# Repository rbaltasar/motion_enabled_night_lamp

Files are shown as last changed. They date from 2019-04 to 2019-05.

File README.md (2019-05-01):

# Introduction and background
This project is about a LED lamp that switches ON and OFF depending on light and motion conditions.
We have all experienced the situation when, at night, nature calls, and we need to make a quick trip to the bathroom. Doing this trip in the darkness can be quite an adventure for some people and in some rooms, but switching the main light of the room might not be the best solution in some cases: annoys the partner, is far away, to bright for your sleepy eyes...
The solution to this problem is easy! A faint light that switches on when you go to the bathroom and switches off once you are already back in bed.
Trying to find such a device on the market, I find many motion-enabled lights. A little bit problematic is that most of them are designed for outdoors lighting, so the light is quite powerful. But the biggest problem is that all these lights are controlled by an unique motion sensor: any motion detected will trigger the light. This could be you waking up and going to the bathroom, or you just moving in the bed.
I could not find any device in the market that focuses on preventing false positives, and this is the most important feature I would ask to a device that might wake me up randomly at night.

# Proposed solution
The ideal solution to this problem would be a device that only goes off when you are already up and walking towards your destination, but does not go off when you or any other thing in your room moves a little bit (e.g: curtains, clothes falling from the chair…).
I want to define a virtual line that  when is crossed, triggers the light. I also want this only happens if we really need some extra light and I want the light to be on as long as I need it to be on and to switch off automatically when I no longer need it.

The first thing that you could think of when I talk about “crossing a virtual line” may be a ultrasonic distance sensor (e.g: HC-SR04). These sensors are based on sound reflection, and they do not work very good with clothes. Besides, having a single sensor keeps high the probabilities of false positives.
This solution consists of two PIR motion sensors placed in such a way that their areas of detection do not overlap. The area of “no detection” will be the virtual line to cross. When both sensors detect a motion and the time difference between the detection is short enough, we can assume that the virtual line has been crossed. If the time difference between detections is larger than a threshold, we can assume that the detection events are sporadic and not related to each other, so no action will be taken. This will exclude most of the false positives that would have triggered a device with a single motion sensor.

To ensure that the lamp only switches on when there is not enough light to see, the system will integrate a light sensor and define a light threshold above which the system will ignore motion events.
Depending on the configured lighting level of the LEDs, when the lamp is on it might trick the light sensor to think that there is enough ambient light to ignore motion events and go to “day” mode. This would trigger an oscillation going on with motion and off because of the light amount. To avoid this irritating behavior, the system is configured to consider the light amount only when the light is off.

To ensure the third requirement of being on until the light is no longer needed, once the system is on, a timer will start. Whenever a new motion event is detected, the timer will be restarted. When a timeout event happens, the light will switch off.

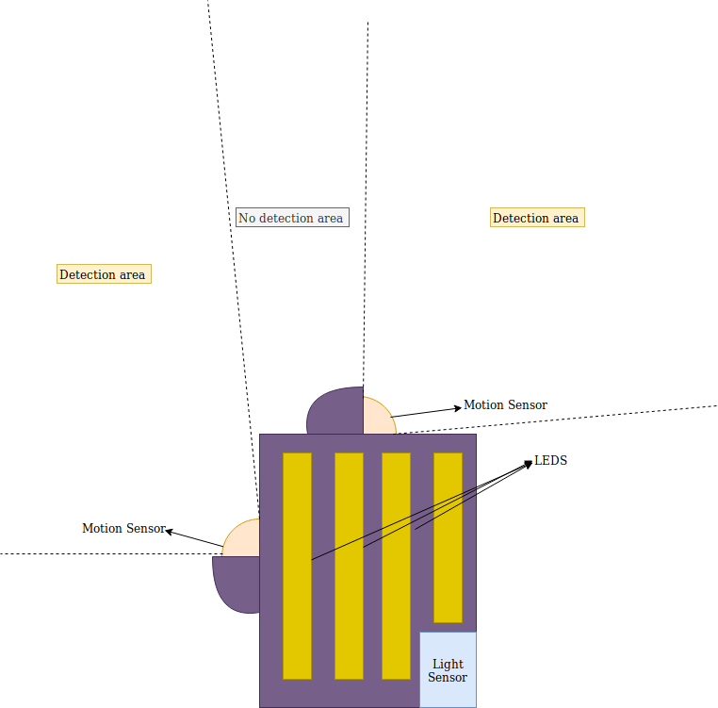
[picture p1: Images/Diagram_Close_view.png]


# The mechanics
This repository contains a 3D model of a box (base, top and cover) that is specifically designed to prevent overlapping of the two motion sensors.
It also leaves an open slot to allow the light sensor to “see”. I would recommend to cover it with a transparent material. The light threshold will need to be adapted to the light conditions of the room and the cover material chosen.

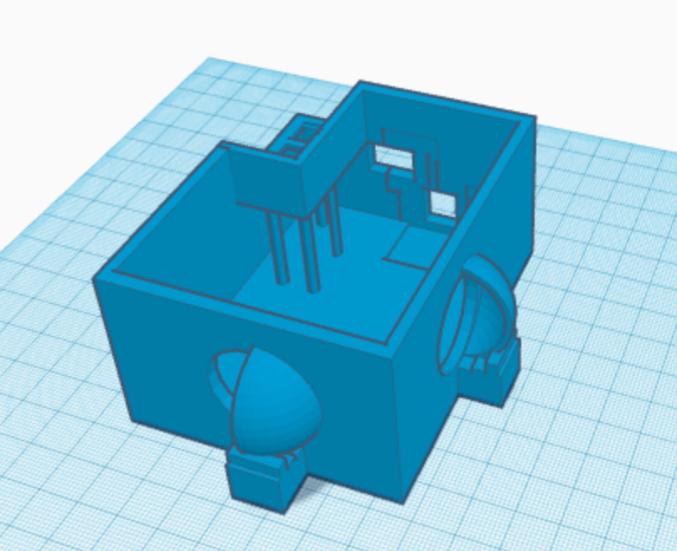
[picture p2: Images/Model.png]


I decided to embed the light in the box, to make a single-piece device, so I also left open slots for the LEDs. It is of course possible to modify the 3D design to place the LEDs in a different way, separate the lighting device from the “control” box…
It should also be doable to use a different lighting device, like a normal map controlled by a relay or an IR-controlled bulb.
I currently only support LED stripe as lighting device, any other method is not yet supported and would need to be implemented.
I might add support for other lighting devices in future updates of the project.

# The hardware
The device consists of the following hardware components:
* Arduino Nano.
* HC-SR501 PIR motion sensor (x2).
* BH1750 light sensor.
* WS2812B led stripe and 5v power supply. More information about how to handle and power this led stripe: https://www.pololu.com/product/2547
* 330 Ohm resistor.

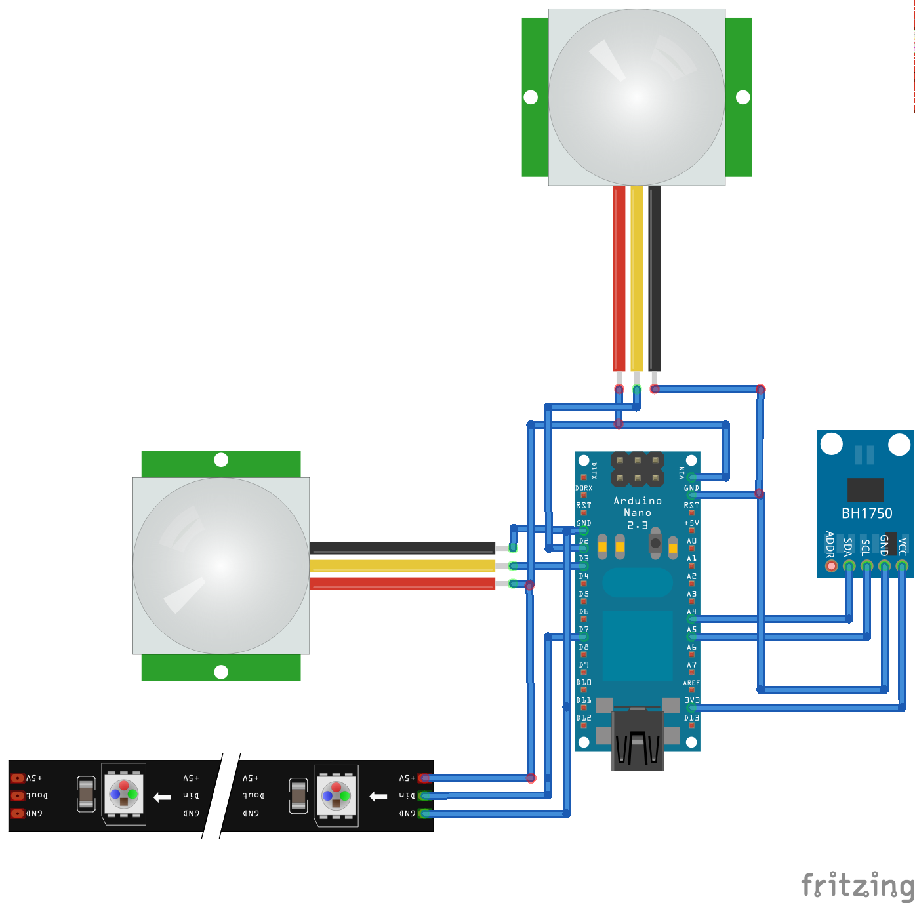
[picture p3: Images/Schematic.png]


# Software & Configuration
To configure the software and flash it into your Arduino, follow the next steps:
1. Clone this repository. Remember to do it recursively to get also the FastLED library.
2. Open the configuration file “config.h” and change the following parameters for your use case:
* NUM_LEDS: number of leds in your LED stripe. By default X LEDs fit in the given 3D model.
* LIGHT_THRESHOLD: above this value, the device is in “Day” mode and will ignore motion events. It is recommended to measure the light level in your room with the debug traces to find the right value.
* DETECTION_INTERVAL: maximum time difference between motion detection of each of the sensors to assume that the virtual line was crossed.
* DEBUG_ENABLED:
  * ON :enables the traces printed in the Serial console.
  * OFF: disables them.
* LIGHT_VALUE_[R,G,B]: defines the (R,G,B) levels of the light.
* STARTUP_EFFECT:
  * ON: enables a colorful effect when the system is powered ON.
  * OFF: disables the effect.
* LIGHT_EFFECT:
  * 0: no effect.
  * 1: led array effect. (DELAY_ARRAY has to be configured as well then)
  * 2: fade effect. (DELAY_FADE has to be configured as well then)
* KEEP_ON_CONDITION:
  * SINGLE_MOTION: once the light is ON, a motion event detected by either of the sensors will restart the timer.
  * DOUBLE_MOTION: once the light is ON, the timer will be restarted only if the ON condition is triggered again (both sensors detect motion within a defined time).
3. Flash the software into the Arduino.

# Final result
It is not the prettiest home automation gadget, but it does its job.
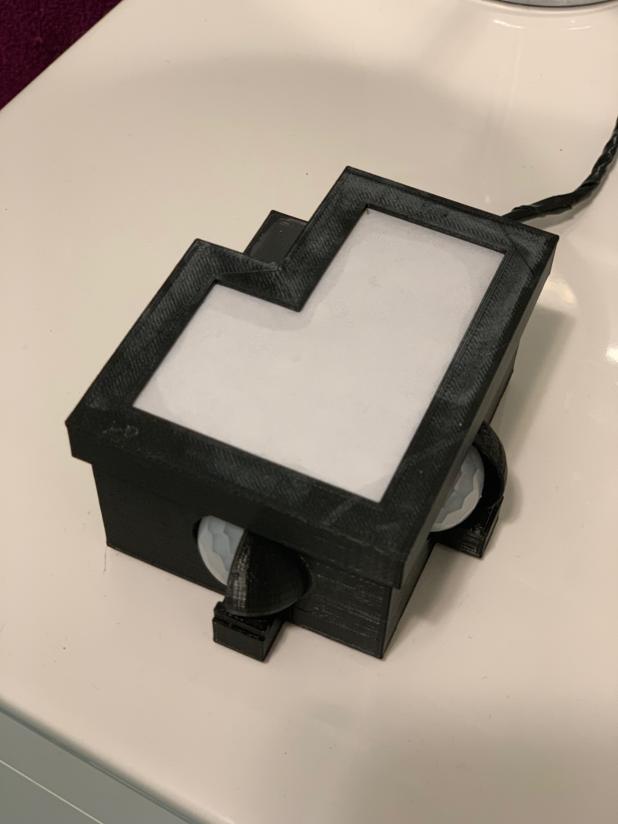
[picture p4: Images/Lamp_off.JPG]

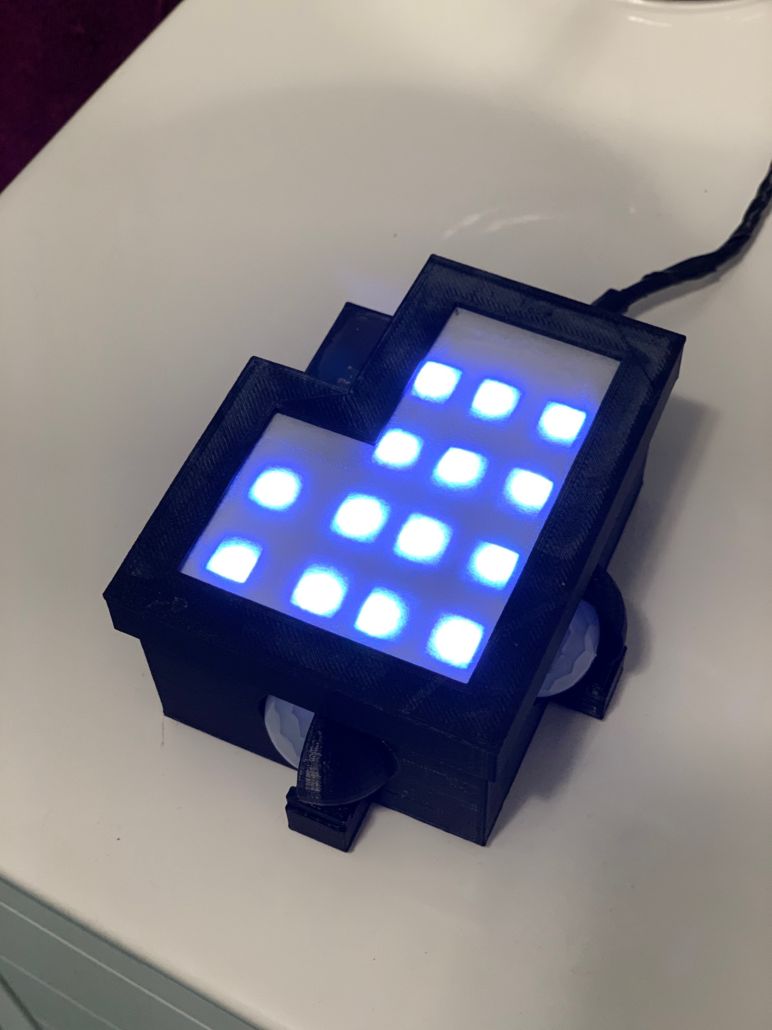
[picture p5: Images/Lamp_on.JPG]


Here a video of the lamp doing its thing:
https://youtu.be/2kOvvQYK9II

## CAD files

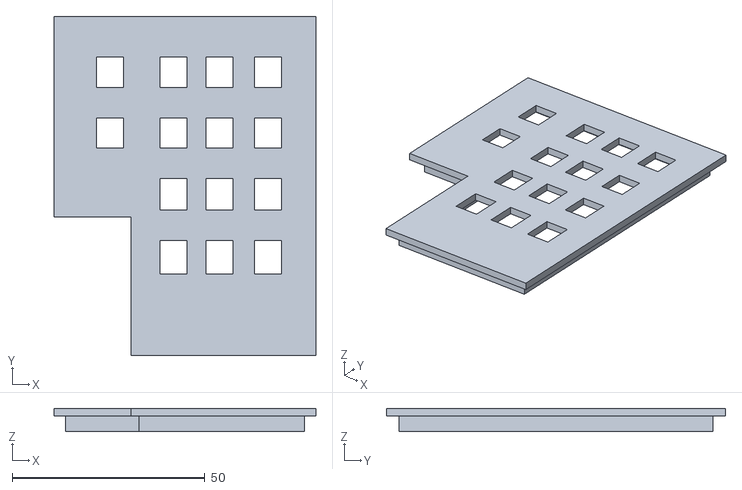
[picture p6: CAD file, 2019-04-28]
3D Model/Night lamp top.stl
68.0 x 88.0 x 6.00

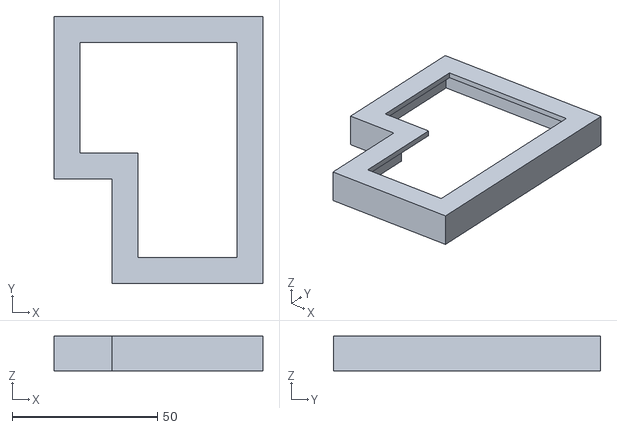
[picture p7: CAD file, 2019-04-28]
3D Model/Night lamp cover.stl
72.0 x 92.0 x 12.0

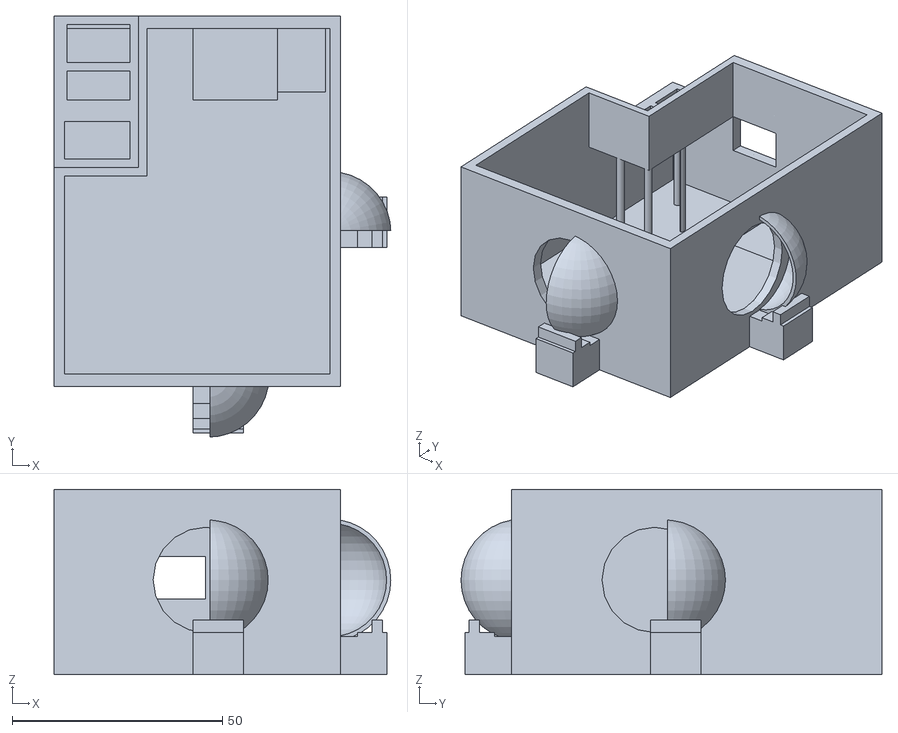
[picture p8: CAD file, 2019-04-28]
3D Model/Night lamp bottom.stl
80.0 x 100.0 x 44.0

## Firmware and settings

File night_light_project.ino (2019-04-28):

#include <Wire.h>
#include <BH1750.h>
#include <FastLED.h>
#include "config.h"

/* Light sensor */
BH1750 lightMeter;
float light_amount = 0;

/* Led stripe */
CRGB leds[NUM_LEDS];

/* State variables */
unsigned long volatile last_detection[2];
unsigned long last_activation = 99999;
unsigned long last_iteration = 0;
bool light_state = false;

void setup()
{
//#if (DEBUG_ENABLED == 1)
  Serial.begin(115200);
//#endif

  /* Attach door interrupt callback */
  attachInterrupt(digitalPinToInterrupt(PRESENCE_SENSOR_1), presence_sensor_1_isr, RISING);
  attachInterrupt(digitalPinToInterrupt(PRESENCE_SENSOR_2), presence_sensor_2_isr, RISING);

  /* Do hardware setup */
  setup_hardware();

  /* Reset state variables */
  last_detection[0] = 0;
  last_detection[1] = 0;

#if (STARTUP_EFFECT == 1)
  /*Do startup effect */
  startup_effect();
#endif
  
}


/* Configure the hardware */
void setup_hardware()
{

  /* In-built LED */
  pinMode(LED_BUILTIN, OUTPUT);     // Initialize the BUILTIN_LED pin as an output
  digitalWrite(LED_BUILTIN, HIGH); //This means led OFF

 /* Initialize I2C bus */
  Wire.begin();
  lightMeter.begin();

  /* Initialize LED controller */
  FastLED.addLeds<WS2812, LED_PIN, COLOR_MODE>(leds, NUM_LEDS);

#if (DEBUG_ENABLED == 1)
  Serial.println("Hardware setup completed");
#endif
}

#if (STARTUP_EFFECT == 1)
void startup_effect()
{
  for(uint8_t i = 0; i < NUM_LEDS; i++)
  {
    leds[i] = CRGB(255,0,0);
    FastLED.show();
    delay(50);
  }

  for(uint8_t i = 0; i < NUM_LEDS; i++)
  {
    leds[i] = CRGB(0,255,0);
    FastLED.show();
    delay(50);
  }
  
  for(uint8_t i = 0; i < NUM_LEDS; i++)
  {
    leds[i] = CRGB(0,0,255);
    FastLED.show();
    delay(50);
  }

  for(uint8_t i = 0; i < NUM_LEDS; i++)
  {
    leds[i] = CRGB(0,0,0);
    FastLED.show();
    delay(50);
  }
}
#endif

/* Get the amount of light */
float get_light_amount()
{
  light_amount = lightMeter.readLightLevel();

#if (DEBUG_ENABLED == 1)
  Serial.print("Light amount: ");
  Serial.println(light_amount);
#endif

  return light_amount;
}

void presence_sensor_1_isr()
{
//#if (DEBUG_ENABLED == 1)
  Serial.println("Interrupt 1 detected");
//#endif
  last_detection[0] = millis();
  
}

void presence_sensor_2_isr()
{
//#if (DEBUG_ENABLED == 1)
  Serial.println("Interrupt 2 detected");
//#endif
  last_detection[1] = millis();
  
}

void led_array_effect(bool state)
{
  if(state)
  {  
    for(uint8_t i = 0; i < NUM_LEDS; i++)
    {
      leds[i] = CRGB(LIGHT_VALUE_R,LIGHT_VALUE_G,LIGHT_VALUE_B);
      FastLED.show();
      delay(DELAY_ARRAY);
    } 
  }
  else
  {
    for(uint8_t i = 0; i < NUM_LEDS; i++)
    {
      leds[i] = CRGB(0,0,0);
      FastLED.show();
      delay(DELAY_ARRAY);
    } 
  }
}

void fade_effect(bool state)
{

  bool exitCondition = false;

  if(state)
  {
    uint8_t step_r = 0;
    uint8_t step_g = 0;
    uint8_t step_b = 0;
    do
    { 
      for(uint8_t i = 0; i < NUM_LEDS; i++) 
      {
        leds[i] = CRGB(step_r,step_g,step_b);
      }

      ++step_r > LIGHT_VALUE_R ? step_r = LIGHT_VALUE_R : step_r = step_r;
      ++step_g > LIGHT_VALUE_G ? step_g = LIGHT_VALUE_G : step_g = step_g;
      ++step_b > LIGHT_VALUE_B ? step_b = LIGHT_VALUE_B : step_b = step_b;

      if( (step_r == LIGHT_VALUE_R) && (step_g == LIGHT_VALUE_G) && (step_b == LIGHT_VALUE_B) ) exitCondition = true;
      
      FastLED.show();
      delay(DELAY_FADE);
    } while(!exitCondition);
  }
  else
  {
    uint8_t step_r = LIGHT_VALUE_R;
    uint8_t step_g = LIGHT_VALUE_G;
    uint8_t step_b = LIGHT_VALUE_B;
    do
    { 
      for(uint8_t i = 0; i < NUM_LEDS; i++) 
      {
        leds[i] = CRGB(step_r,step_g,step_b);
      }

      --step_r <= 1 ? step_r = 1 : step_r = step_r;
      --step_g <= 1 ? step_g = 1 : step_g = step_g;
      --step_b <= 1 ? step_b = 1 : step_b = step_b;

      if( (step_r == 1) && (step_g == 1) && (step_b == 1) )
      {
        exitCondition = true;
        for(uint8_t i = 0; i < NUM_LEDS; i++) 
        {
          leds[i] = CRGB(0,0,0);
        }
      }
      
      FastLED.show();
      delay(DELAY_FADE);
    } while(!exitCondition); 
  }
}


void set_lights(bool state)
{

  if(state != light_state)
  {
    light_state = state;

    if(state)
    {
#if (DEBUG_ENABLED == 1)
      Serial.println("LIGHTS ON");
#endif

#if (LIGHT_EFFECT == 1)
      led_array_effect(state);
#elif (LIGHT_EFFECT == 2)
      fade_effect(state);
#else
      for(uint8_t i = 0; i < NUM_LEDS; i++)
      {
        leds[i] = CRGB(LIGHT_VALUE_R,LIGHT_VALUE_G,LIGHT_VALUE_B);        
      }
      FastLED.show();
#endif      
    }
    else
    {
#if (DEBUG_ENABLED == 1)
      Serial.println("LIGHTS OFF");
#endif

#if (LIGHT_EFFECT == 1)
      led_array_effect(state);
#elif (LIGHT_EFFECT == 2)
      fade_effect(state);
#else
      for(uint8_t i = 0; i < NUM_LEDS; i++)
      {
        leds[i] = CRGB(0,0,0);        
      }
      FastLED.show();
#endif
    }      
  }   
}

void apply_logic()
{

  /* Evaluate only if the activation time has expired */
  unsigned long current_time = millis();  
  if(abs(current_time - last_activation) > ACTIVE_TIME)
  {    
    /* Compute the time difference between detections */  
    noInterrupts();
    unsigned long detection_difference_0 = abs(last_detection[0] - last_detection[1]);
    /* Compute the time since the last detection */
    unsigned long time_since_detection_0 = current_time - last_detection[0];
    unsigned long time_since_detection_1 = current_time - last_detection[1];   
    interrupts(); 

    /* If the light is already ON */
    if(light_state)
    {
      /* Decide to continue ON */
#if (KEEP_ON_CONDITION == 0)
      if( (time_since_detection_0 < DETECTION_INTERVAL) || (time_since_detection_1 < DETECTION_INTERVAL) )
#else
      if( (time_since_detection_0 < DETECTION_INTERVAL) && (time_since_detection_1 < DETECTION_INTERVAL) )
#endif
      {        
        last_activation = current_time;        
      }
      /* Decide to switch OFF */
      else
      {
#if (DEBUG_ENABLED == 1)
        Serial.println("Large difference between detections. Switching off");
        Serial.println(time_since_detection_0);
        Serial.println(time_since_detection_1);
#endif
        set_lights(false);
      } 
    }
    /* If the light is OFF */
    else
    {
      /* Get light amount */
      float light = get_light_amount();  
      
      /* Decide to switch ON */
      if( (time_since_detection_0 < DETECTION_INTERVAL) && (time_since_detection_1 < DETECTION_INTERVAL) && (light < LIGHT_THRESHOLD) )
      {
        last_activation = current_time;  
        set_lights(true);      
      }
    }       
  }
}

#if (DEBUG_ENABLED == 1)
void print_status()
{
  unsigned long current_time = millis(); 
  
  if( ((current_time - last_detection[0]) < DETECTION_INTERVAL) && ((current_time - last_detection[1]) < DETECTION_INTERVAL ) )
  {
    Serial.print("###################   ###################");
  }

  else if( (current_time - last_detection[0]) < DETECTION_INTERVAL )
  {
    Serial.print("###################");
  }
  else if( (current_time - last_detection[1]) < DETECTION_INTERVAL )
  {
    Serial.print("                      ###################");
  }

  Serial.println("");
  
}
#endif


void loop() {

  unsigned long current_time = millis();  
  
  if(current_time - last_iteration > LOOP_TIME)
  {
    
    last_iteration = current_time;    
    apply_logic();
#if (DEBUG_ENABLED == 1)
    print_status();
#endif
  }

  delay(LOOP_TIME);  

}

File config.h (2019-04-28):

#if !defined CONFIG_H
#define CONFIG_H

/* Hardware configuration */
#define NUM_LEDS 14 //Number of leds
#define PRESENCE_SENSOR_1 3
#define PRESENCE_SENSOR_2 2
#define LED_PIN 7

/* Configuration parameters */
#define ACTIVE_TIME 30000 //Minimum amount of time that the lamp is ON
#define DETECTION_INTERVAL 10000 //Maximum time difference between motion events to switch ON
#define LIGHT_THRESHOLD 1 //Maximum light amount to switch lights ON
#define STARTUP_EFFECT 1 //[0]: No startup effect / [1]: Startup effect
#define LIGHT_EFFECT 2 //[0]: No effect / [1]: Led Array / [2]: Fade
#define KEEP_ON_CONDITION 1 //[0]: SINGLE_MOTION / [1]: DOUBLE_MOTION

/* Effects parameters */
#define DELAY_FADE 70
#define DELAY_ARRAY 100

/* Led lighting */
#define LIGHT_VALUE_R 150//200
#define LIGHT_VALUE_G 200//180
#define LIGHT_VALUE_B 200//100

/* Other parameters */
#define LOOP_TIME 1000 //Sleep delay in main loop (power saving)
#define COLOR_MODE GRB//Could be GRB

/* Debugging */
#define DEBUG_ENABLED 1

#endif
